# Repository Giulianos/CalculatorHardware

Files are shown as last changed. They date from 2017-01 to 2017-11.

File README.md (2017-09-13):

# Programmable Pocket Calculator Hardware

## Description
This programmable pocket sized calculator has the following features:
  - Credit card size, 8mm thick!
  - ARM Cortex M4 Microcontroller
  - microSD card reader
  - OLED Display
  - 44 mechanical* matrix keyboard (*tactile switches)
  - Lipo battery charging circuit

## Images
- Unsoldered, showing it's thickness
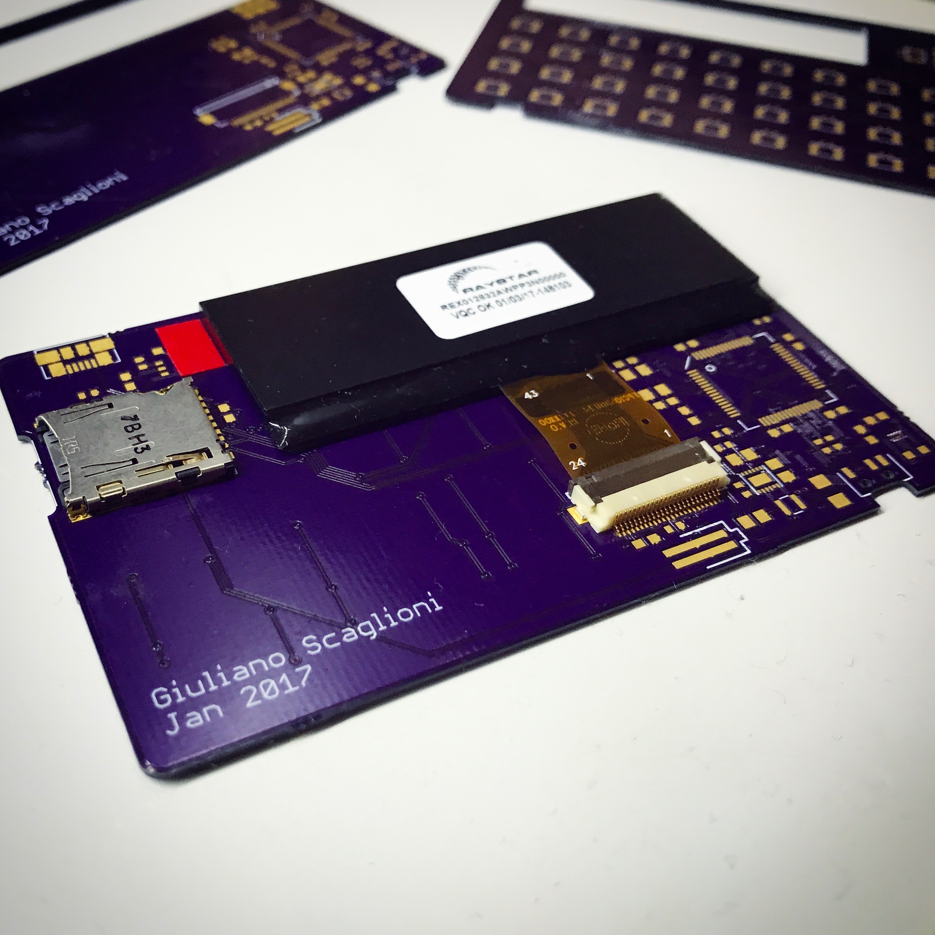
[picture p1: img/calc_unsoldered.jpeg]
Calc is 8mm thick!

- Soldered
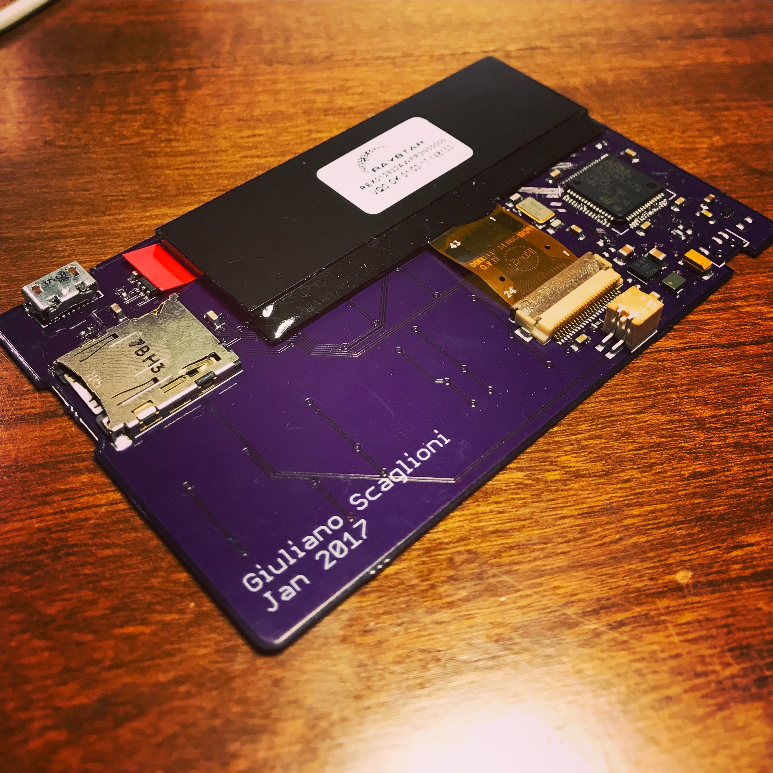
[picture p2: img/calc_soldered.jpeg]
Calc soldered

- Front view of PCB without tactile switches and with OLED in place
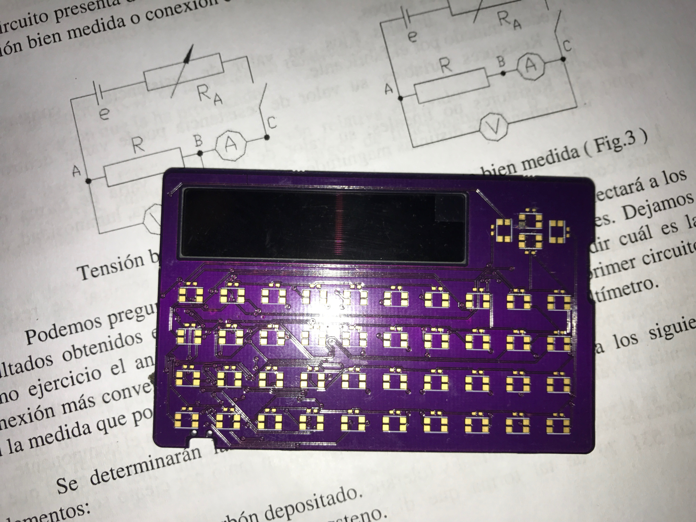
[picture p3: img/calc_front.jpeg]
Front view

- Back view of PCB unsoldered with battery, micro usb and micro sd card reader in place
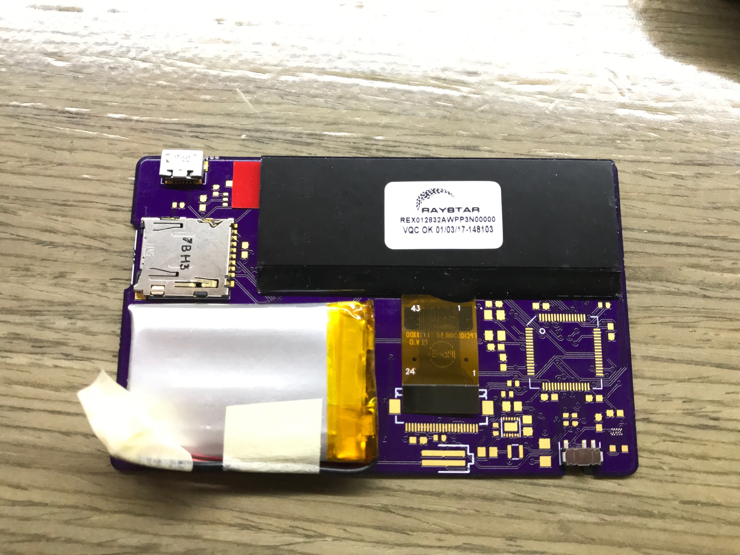
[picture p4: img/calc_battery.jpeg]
Back view

- Altium's 3D Render of the PCB
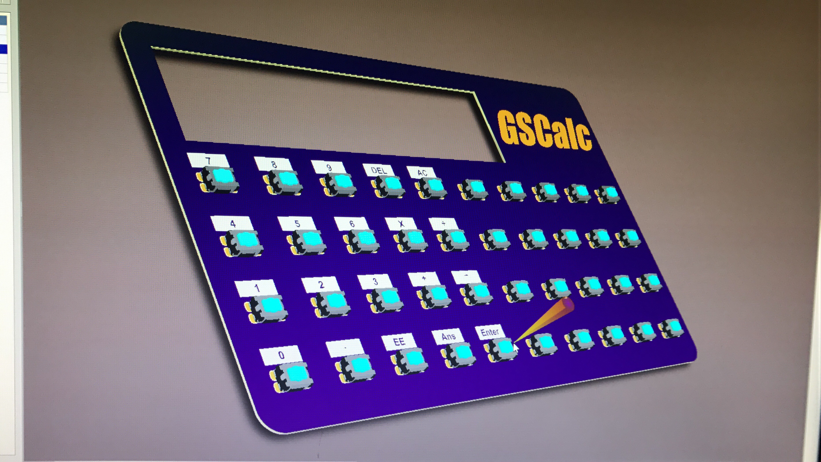
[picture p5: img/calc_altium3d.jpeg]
3D Render


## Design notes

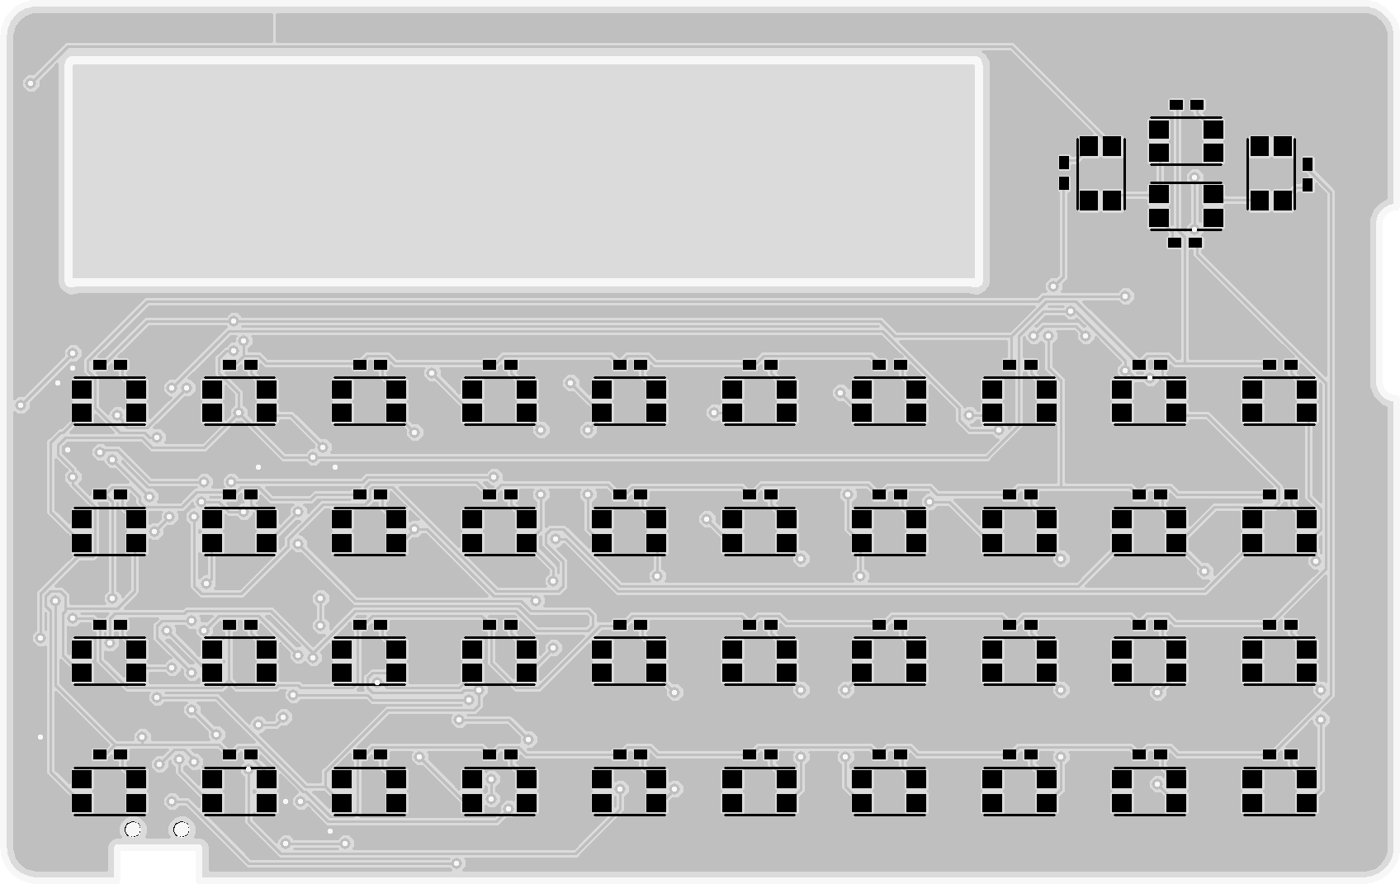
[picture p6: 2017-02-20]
pcbRenderTop.png

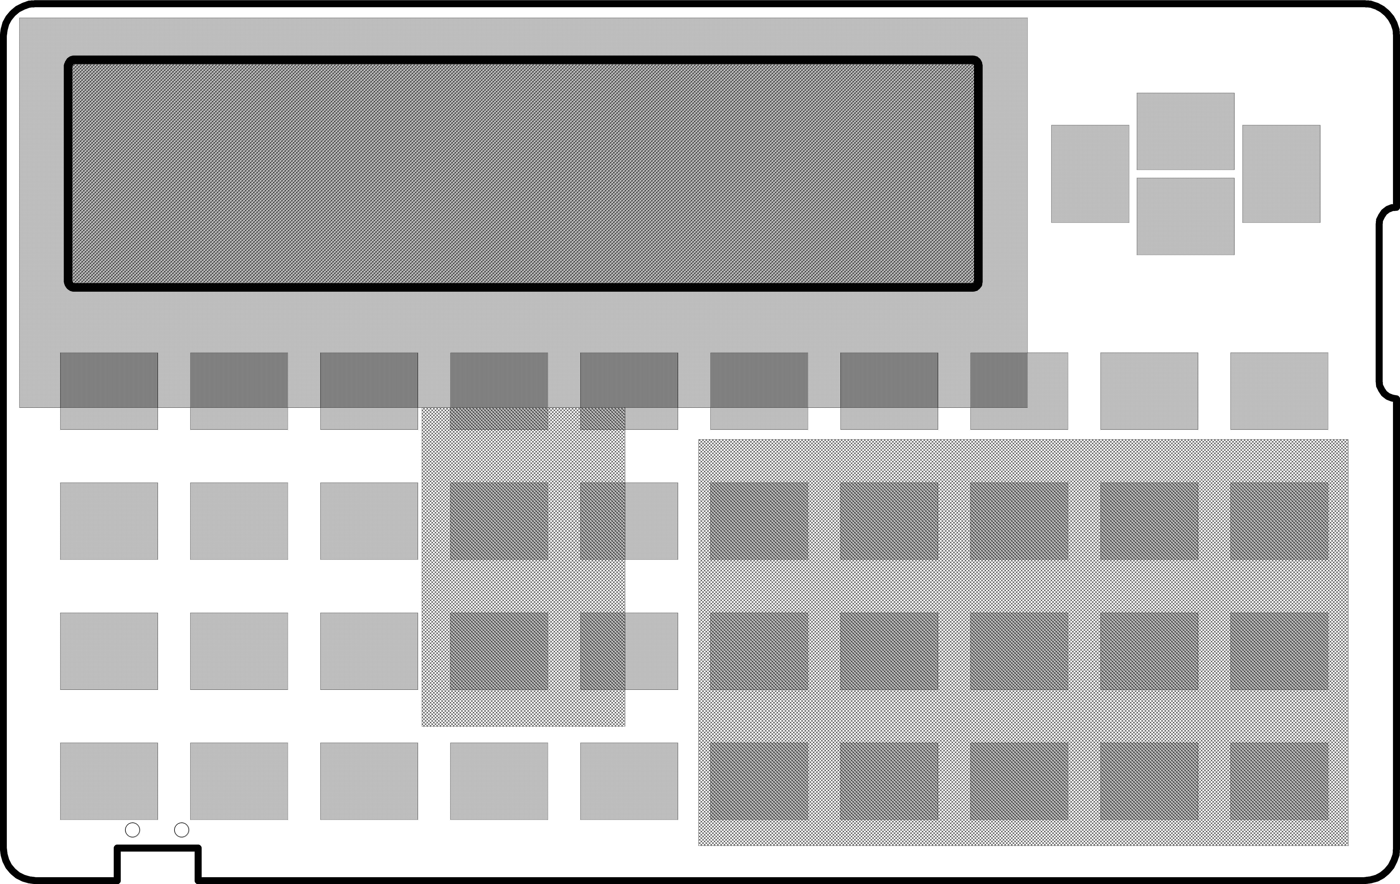
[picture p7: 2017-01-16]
render.png

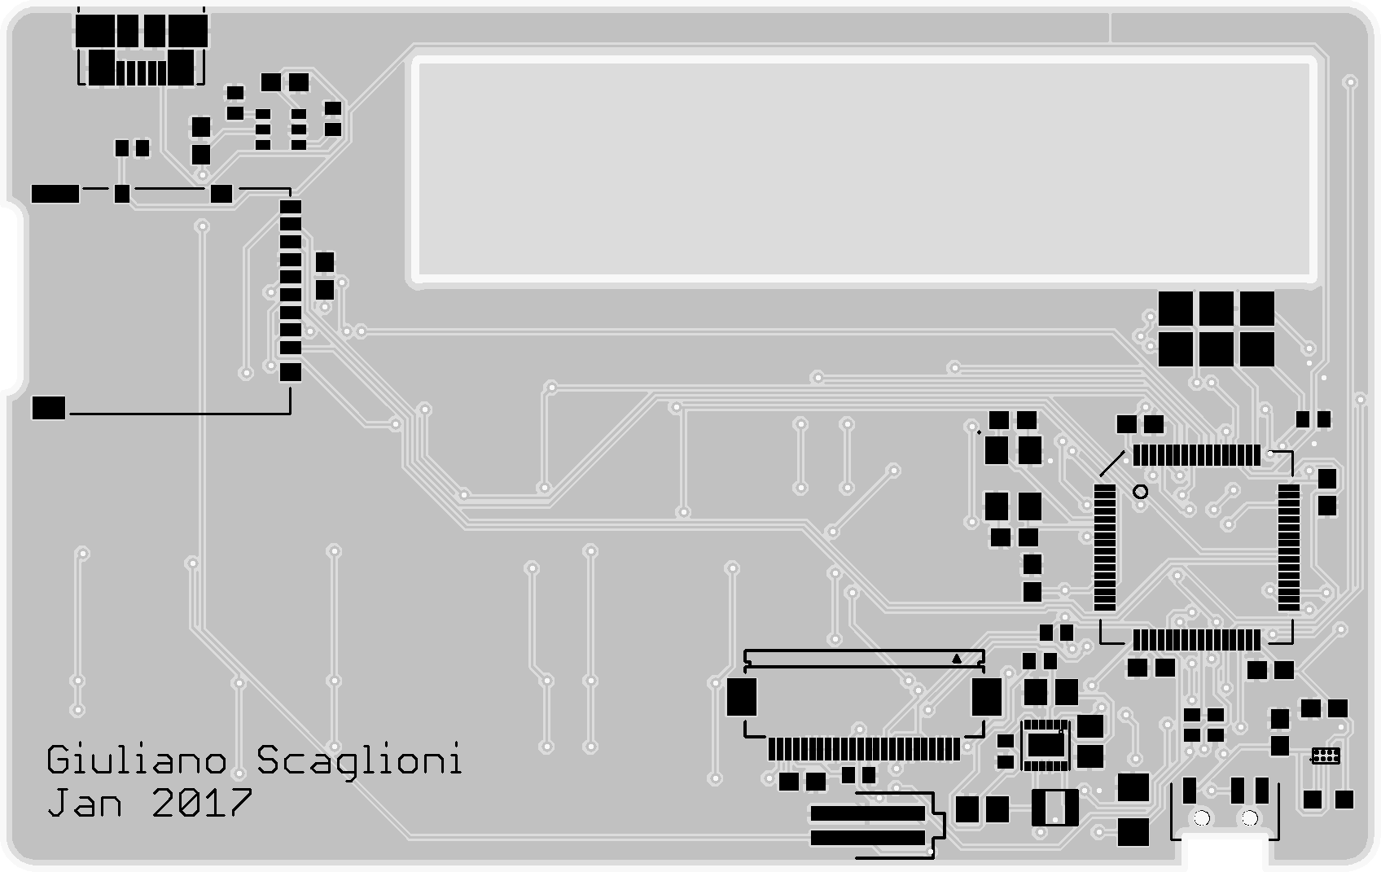
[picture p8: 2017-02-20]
pcbRenderBottom.png

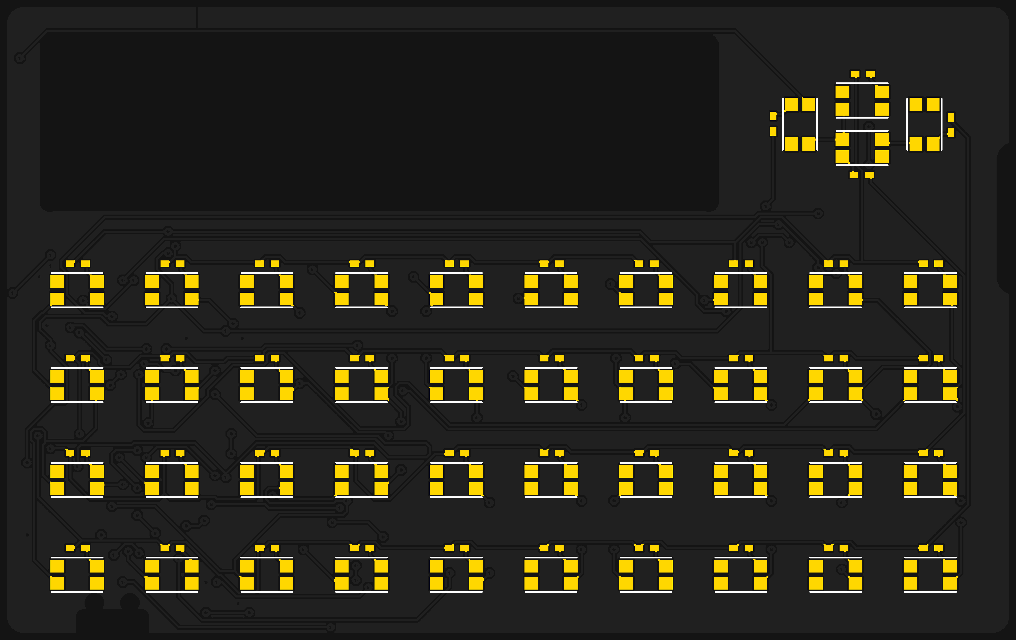
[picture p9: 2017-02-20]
eagleUp/eagleUp_mainboard_board_top.png

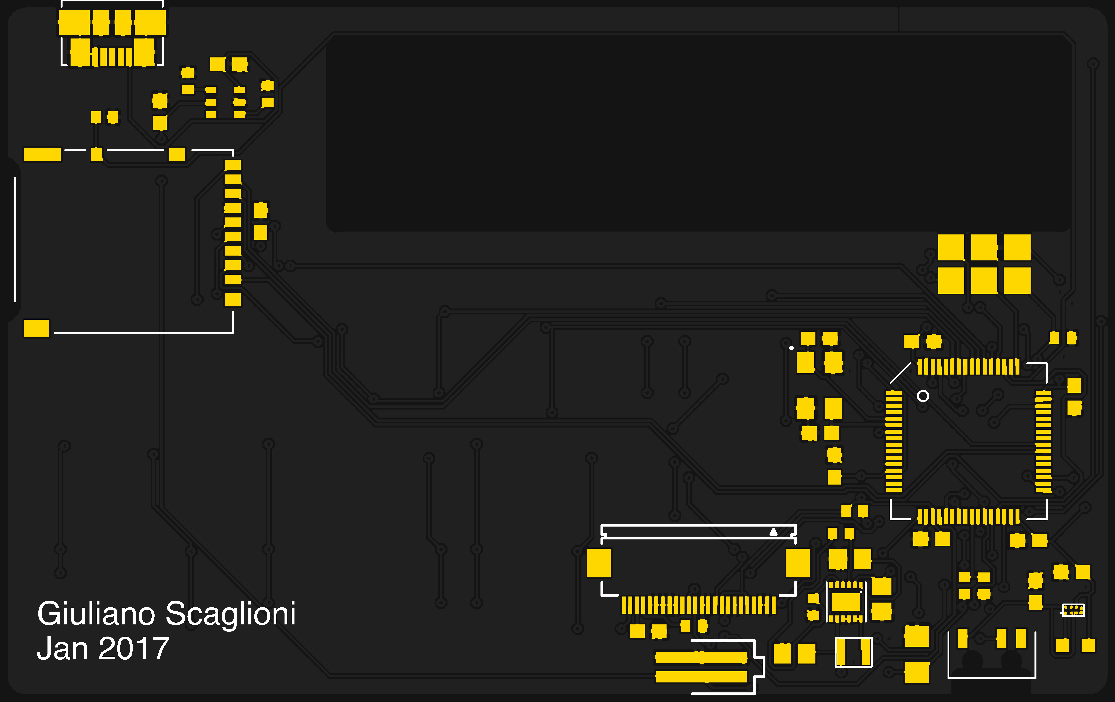
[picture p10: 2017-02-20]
pcbModel/eagleUp_mainboard_bottom_board.png

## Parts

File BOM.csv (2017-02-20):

Item | Valor | Codigo | Cantidad
Resistencia 0402 | 10k | 71-CRCW0402-10K-E3 | 20
Resistencia 0402 | 33k | 71-CRCW040233K0FKED | 10
Resistencia 0402 | 130k | 71-CRCW0402-130K-E3 | 10
Resistencia 0402 | 330k | 594-MCS04020C3303FE0 | 10
Resistencia 0402 | 300k | 71-CRCW0402-300K-E3 | 10
Resistencia 0402 | 1.2k | 71-CRCW0402-1.2K-E3 | 10
Resistencia 0603 | 910k | 71-CRCW0603-910K-E3 | 10
Capacitor 0603 | 18pF | 81-GRM39C180J50 | 10
Capacitor 0603 | 100nF | 80-C0603C104K4P | 20
Capacitor 0603 | 4.7uF | 81-GRM18R60J475KE19D | 10
Capacitor 0603 | 1uF | 81-GRM39R105K6.3 | 10
Capacitor 0603 | 10uF | 81-GRM188C80J106KA3D | 10
Capacitor 0805 | 10uF | 81-GRM21BR61A106KE19 | 10
Capacitor 0805 | 4.7uF | 81-GCM21BR71C475KA3L | 10
Capacitor 1206 Tant | 10uF | 80-T495A106K10ATE1K8 | 3
Inductor | 2.2uH | 81-1285AS-H-2R2MP2 | 5
Inductor | 4.7uH | 810-VLS252010HBU4R7M | 3
Crystal | 8MHz | 581-CX5032SA08HPSTZ1 | 3
Schotky Diode |  | 863-NSR05T40XV2T5G | 50
Momentary Switch |  | 710-434153017835 | 50
STM32 |  | 511-STM32L471RGT6 | 1
Card Reader |  | 798-DM3AT-SF-PEJM5 | 2
USB Connector |  | 538-47346-1001 | 2
Power Switch |  | 688-SSSS810701 | 3
OLED Display |  | 668-REX012832AWPP3N | 1
FFC Display Connector |  | 798-FH12-24S-0.5SH55 | 2
Buck 3.3v voltage regulator |  | 595-TPS627431YFPR | 2
Boost 13v voltage regulator |  | 511-STOD1317BTPUR | 2
Battery Charger Controller |  | 595-BQ21040DBVR | 2
Battery Connector |  | 538-87438-0243 | 3
Battery Wire Housing |  | 538-87439-0200 | 3
Battery Wire Contact |  | 538-87421-0000-CT | 100

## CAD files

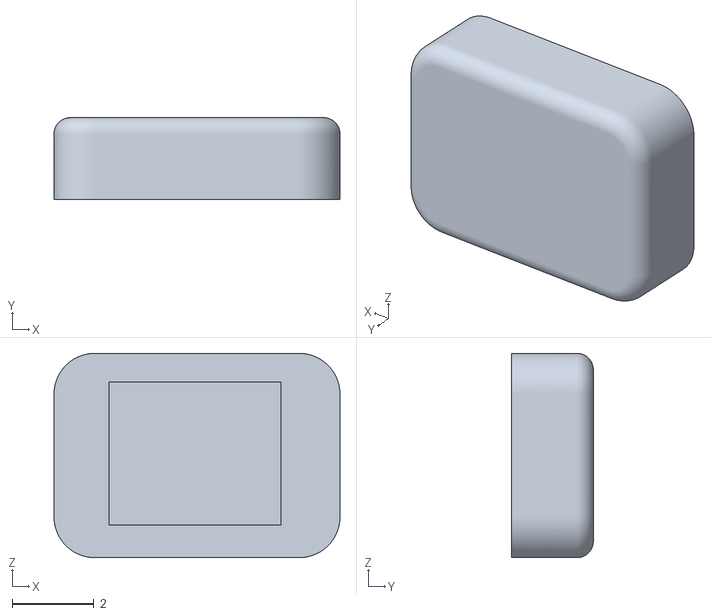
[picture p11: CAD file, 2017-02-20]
eagleUp/keyModel.stl
7.00 x 2.00 x 5.00

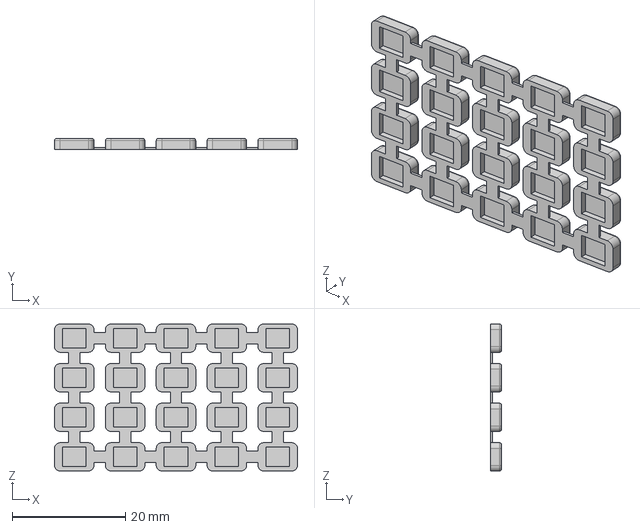
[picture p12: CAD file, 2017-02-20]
keypadModel.step
43.0 x 2.00 x 26.0 mm

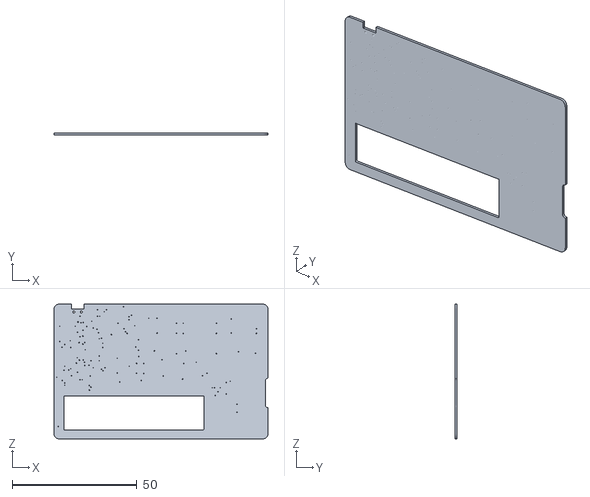
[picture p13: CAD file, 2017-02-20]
pcbModel.obj
85.7 x 0.8 x 54.0

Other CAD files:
keypadMatrixModel.stl

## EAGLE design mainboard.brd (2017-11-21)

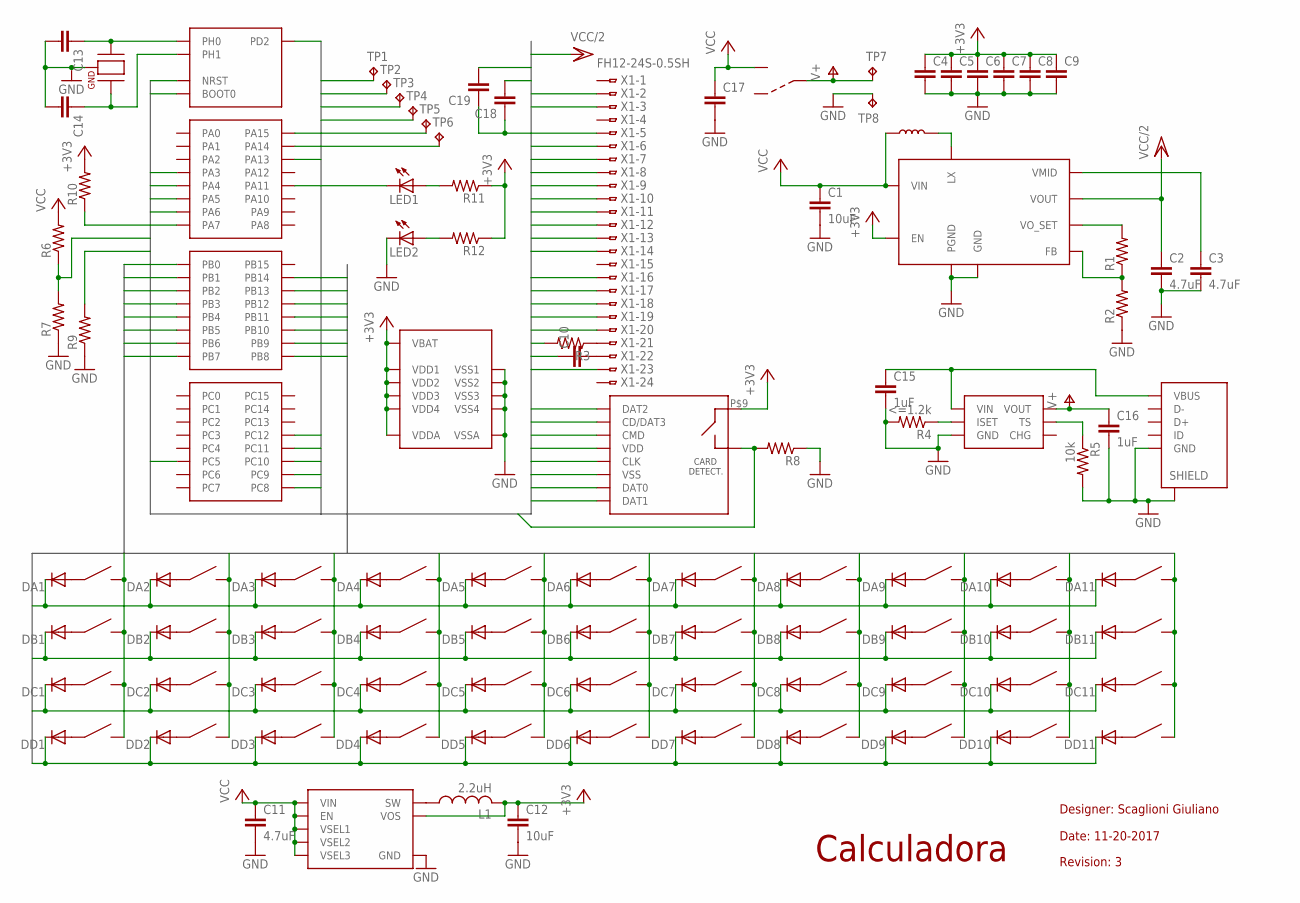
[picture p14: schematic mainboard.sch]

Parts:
BTA1, BTA2, BTA3, BTA4, BTA5, BTA6, BTA7, BTA8, BTA9, BTA10, BTA11: WURTH_SWITCH; WURTH_SWITCH_SMD
BTB1, BTB2, BTB3, BTB4, BTB5, BTB6, BTB7, BTB8, BTB9, BTB10, BTB11: WURTH_SWITCH; WURTH_SWITCH_SMD
BTC1, BTC2, BTC3, BTC4, BTC5, BTC6, BTC7, BTC8, BTC9, BTC10, BTC11: WURTH_SWITCH; WURTH_SWITCH_SMD
BTD1, BTD2, BTD3, BTD4, BTD5, BTD6, BTD7, BTD8, BTD9, BTD10, BTD11: WURTH_SWITCH; WURTH_SWITCH_SMD
C1: 10uF; C0805
C2, C3: 4.7uF; C0805
C4, C5, C6, C7, C8, C9, C10, C18, C19: C-EUC0603; C0603
C11: 4.7uF; C0603
C12: 10uF; C0603
C13, C14: CC0603; C0603
C15, C16: 1uF; C0603
C17: CC1206; C1206
DA1, DA2, DA3, DA4, DA5, DA6, DA7, DA8, DA9, DA10, DA11: DIODE-SOD523; SOD523
DB1, DB2, DB3, DB4, DB5, DB6, DB7, DB8, DB9, DB10, DB11: DIODE-SOD523; SOD523
DC1, DC2, DC3, DC4, DC5, DC6, DC7, DC8, DC9, DC10, DC11: DIODE-SOD523; SOD523
DD1, DD2, DD3, DD4, DD5, DD6, DD7, DD8, DD9, DD10, DD11: DIODE-SOD523; SOD523
L1: 2.2uH; L2012C
LED1, LED2: LED_ESML0603; LED_SML0603
R1, R2, R3, R6, R7, R8, R9, R10, R11, R12: R-US_R0402; R0402
R4: <=1.2k; R0402
R5: 10k; R0402
TP1, TP2, TP3, TP4, TP5, TP6, TP7, TP8: TPTP20SQ; TP20SQ
U$1: STM32L471RGT6; LQFP64
U$2: DM3AT-SF-PEJM5; DM3AT-SF-PEJM5_MICROSDREADER
U$3: MOLEX_47346-1001
U$4: STOD1317BTPUR; DFN12L
U$5: VLS252010HBU
U$6: TPS627431YFPR; BGA8
U$7: CX5032SA; CRYSTAL_5X3.2
U$8: BQ21040DBVR; 6-SOT-23
U$9: ALPS_SSSS810701
X1: FH12-24S-0.5SH

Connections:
+3V3: C4.1, C5.1, C6.1, C7.1, C8.1, C9.1, C12.1, C18.2, L1.2, R10.2, R11.1, R12.1, TP1.TP, U$1.P$1 (VBAT), U$1.P$13 (VDDA), U$1.P$19 (VDD1), U$1.P$32 (VDD2), U$1.P$48 (VDD3), U$1.P$64 (VDD4), U$2.P$4 (VDD), U$2.P$9, U$4.P6 (EN), U$6.C2 (VOS), X1.5, X1.9
BAT_SENS: R6.1, R7.2, U$1.P$25 (PC5)
BOOT0: R9.2, TP5.TP, U$1.P$60 (BOOT0)
GND: C1.2, C2.2, C3.2, C4.2, C5.2, C6.2, C7.2, C8.2, C9.2, C10.1, C11.2, C12.2, C13.2, C14.2, C15.2, C16.2, C17.2, C18.1, C19.1, LED2.C, R2.1, R3.2, R4.2, R5.2, R7.1, R8.1, R9.1, TP4.TP, TP8.TP, U$1.P$12 (VSSA), U$1.P$18 (VSS1), U$1.P$31 (VSS2), U$1.P$47 (VSS3), U$1.P$63 (VSS4), U$2.P$6 (VSS), U$3.MECH1, U$3.MECH2, U$3.MECH3, U$3.MECH4, U$3.MECH5, U$3.MECH6, U$3.P$5 (GND), U$4.P4 (GND), U$4.P9 (PGND), U$4.P10 (PGND), U$6.B2 (GND), U$7.P$2 (GND), U$7.P$4 (GND), U$8.P$5 (GND), X1.2, X1.3, X1.6, X1.7, X1.11, X1.12, X1.16, X1.17, X1.18, X1.19, X1.20
KEYCOL0: BTA1.P$2, BTA1.P$4, BTB1.P$2, BTB1.P$4, BTC1.P$2, BTC1.P$4, BTD1.P$2, BTD1.P$4, U$1.P$26 (PB0)
KEYCOL1: BTA2.P$2, BTA2.P$4, BTB2.P$2, BTB2.P$4, BTC2.P$2, BTC2.P$4, BTD2.P$2, BTD2.P$4, U$1.P$27 (PB1)
KEYCOL2: BTA3.P$2, BTA3.P$4, BTB3.P$2, BTB3.P$4, BTC3.P$2, BTC3.P$4, BTD3.P$2, BTD3.P$4, U$1.P$28 (PB2)
KEYCOL3: BTA4.P$2, BTA4.P$4, BTB4.P$2, BTB4.P$4, BTC4.P$2, BTC4.P$4, BTD4.P$2, BTD4.P$4, U$1.P$55 (PB3)
KEYCOL4: BTA5.P$2, BTA5.P$4, BTB5.P$2, BTB5.P$4, BTC5.P$2, BTC5.P$4, BTD5.P$2, BTD5.P$4, U$1.P$56 (PB4)
KEYCOL5: BTA6.P$2, BTA6.P$4, BTB6.P$2, BTB6.P$4, BTC6.P$2, BTC6.P$4, BTD6.P$2, BTD6.P$4, U$1.P$57 (PB5)
KEYCOL6: BTA7.P$2, BTA7.P$4, BTB7.P$2, BTB7.P$4, BTC7.P$2, BTC7.P$4, BTD7.P$2, BTD7.P$4, U$1.P$58 (PB6)
KEYCOL7: BTA8.P$2, BTA8.P$4, BTB8.P$2, BTB8.P$4, BTC8.P$2, BTC8.P$4, BTD8.P$2, BTD8.P$4, U$1.P$59 (PB7)
KEYCOL8: BTA9.P$2, BTA9.P$4, BTB9.P$2, BTB9.P$4, BTC9.P$2, BTC9.P$4, BTD9.P$2, BTD9.P$4, U$1.P$61 (PB8)
KEYCOL9: BTA10.P$2, BTA10.P$4, BTB10.P$2, BTB10.P$4, BTC10.P$2, BTC10.P$4, BTD10.P$2, BTD10.P$4, U$1.P$62 (PB9)
KEYCOL10: BTA11.P$2, BTA11.P$4, BTB11.P$2, BTB11.P$4, BTC11.P$2, BTC11.P$4, BTD11.P$2, BTD11.P$4, U$1.P$29 (PB10)
KEYROW0: DA1.C, DA2.C, DA3.C, DA4.C, DA5.C, DA6.C, DA7.C, DA8.C, DA9.C, DA10.C, DA11.C
KEYROW1: DB1.C, DB2.C, DB3.C, DB4.C, DB5.C, DB6.C, DB7.C, DB8.C, DB9.C, DB10.C, DB11.C, U$1.P$34 (PB13)
KEYROW2: DC1.C, DC2.C, DC3.C, DC4.C, DC5.C, DC6.C, DC7.C, DC8.C, DC9.C, DC10.C, DC11.C, U$1.P$33 (PB12)
KEYROW3: DD1.C, DD2.C, DD3.C, DD4.C, DD5.C, DD6.C, DD7.C, DD8.C, DD9.C, DD10.C, DD11.C, U$1.P$30 (PB11), U$1.P$35 (PB14)
unnamed: U$4.P11 (LX), U$4.P12 (LX), U$5.P$2
unnamed: R1.1, R2.2, U$4.P5 (FB)
unnamed: R3.1, X1.21
unnamed: R1.2, U$4.P3 (VO_SET)
unnamed: C10.2, X1.22
unnamed: C3.1, U$4.P1 (VMID)
unnamed: L1.1, U$6.A1 (SW)
unnamed: BTA1.P$1, BTA1.P$3, DA1.A
unnamed: BTA2.P$1, BTA2.P$3, DA2.A
unnamed: BTA3.P$1, BTA3.P$3, DA3.A
unnamed: BTA4.P$1, BTA4.P$3, DA4.A
unnamed: BTA5.P$1, BTA5.P$3, DA5.A
unnamed: BTA6.P$1, BTA6.P$3, DA6.A
unnamed: BTA7.P$1, BTA7.P$3, DA7.A
unnamed: BTA8.P$1, BTA8.P$3, DA8.A
unnamed: BTA9.P$1, BTA9.P$3, DA9.A
unnamed: BTA10.P$1, BTA10.P$3, DA10.A
unnamed: BTA11.P$1, BTA11.P$3, DA11.A
unnamed: BTB1.P$1, BTB1.P$3, DB1.A
unnamed: BTB2.P$1, BTB2.P$3, DB2.A
unnamed: BTB3.P$1, BTB3.P$3, DB3.A
unnamed: BTB4.P$1, BTB4.P$3, DB4.A
unnamed: BTB5.P$1, BTB5.P$3, DB5.A
unnamed: BTB6.P$1, BTB6.P$3, DB6.A
unnamed: BTB7.P$1, BTB7.P$3, DB7.A
unnamed: BTB8.P$1, BTB8.P$3, DB8.A
unnamed: BTB9.P$1, BTB9.P$3, DB9.A
unnamed: BTB10.P$1, BTB10.P$3, DB10.A
unnamed: BTB11.P$1, BTB11.P$3, DB11.A
unnamed: BTC1.P$1, BTC1.P$3, DC1.A
unnamed: BTC2.P$1, BTC2.P$3, DC2.A
unnamed: BTC3.P$1, BTC3.P$3, DC3.A
unnamed: BTC4.P$1, BTC4.P$3, DC4.A
unnamed: BTC5.P$1, BTC5.P$3, DC5.A
unnamed: BTC6.P$1, BTC6.P$3, DC6.A
unnamed: BTC7.P$1, BTC7.P$3, DC7.A
unnamed: BTC8.P$1, BTC8.P$3, DC8.A
unnamed: BTC9.P$1, BTC9.P$3, DC9.A
unnamed: BTC10.P$1, BTC10.P$3, DC10.A
unnamed: BTC11.P$1, BTC11.P$3, DC11.A
unnamed: BTD1.P$1, BTD1.P$3, DD1.A
unnamed: BTD2.P$1, BTD2.P$3, DD2.A
unnamed: BTD3.P$1, BTD3.P$3, DD3.A
unnamed: BTD4.P$1, BTD4.P$3, DD4.A
unnamed: BTD5.P$1, BTD5.P$3, DD5.A
unnamed: BTD6.P$1, BTD6.P$3, DD6.A
unnamed: BTD7.P$1, BTD7.P$3, DD7.A
unnamed: BTD8.P$1, BTD8.P$3, DD8.A
unnamed: BTD9.P$1, BTD9.P$3, DD9.A
unnamed: BTD10.P$1, BTD10.P$3, DD10.A
unnamed: BTD11.P$1, BTD11.P$3, DD11.A
unnamed: C13.1, U$1.P$5 (PH0), U$7.P$1 (P1)
unnamed: C14.1, U$1.P$6 (PH1), U$7.P$3 (P2)
unnamed: C15.1, U$3.P$1 (VBUS), U$8.P$6 (VIN)
unnamed: R5.1, U$8.P$1 (TS)
unnamed: R4.1, U$8.P$4 (ISET)
unnamed: LED1.A, R11.2
unnamed: LED1.C, U$1.P$44 (PA11)
unnamed: LED2.A, R12.2
NRST: R10.1, TP6.TP, U$1.P$7 (NRST)
PA3: U$1.P$17 (PA3), X1.10
PA13: TP2.TP, U$1.P$46 (PA13)
PA14: TP3.TP, U$1.P$49 (PA14)
SD_CLK: U$1.P$53 (PC12), U$2.P$5 (CLK)
SD_CMD: U$1.P$54 (PD2), U$2.P$3 (CMD)
SD_DAT0: U$1.P$39 (PC8), U$2.P$7 (DAT0)
SD_DAT1: U$1.P$40 (PC9), U$2.P$8 (DAT1)
SD_DAT2: U$1.P$51 (PC10), U$2.P$1 (DAT2)
SD_DAT3: U$1.P$52 (PC11), U$2.P$2 (CD/DAT3)
SD_SWITCH: R8.2, U$1.P$50 (PA15), U$2.P$10
SPI_CS: U$1.P$20 (PA4), X1.8
SPI_MISO: U$1.P$22 (PA6)
SPI_MOSI: U$1.P$23 (PA7), X1.14
SPI_SCK: U$1.P$21 (PA5), X1.13
V+: C16.1, TP7.TP, U$8.P$2 (VOUT), U$9.P$1 (COM)
VCC: C1.1, C11.1, C17.1, R6.2, U$4.P8 (VIN), U$5.P$1, U$6.A2 (VIN), U$6.B1 (EN), U$6.C1 (VSEL1), U$6.D1 (VSEL2), U$6.D2 (VSEL3), U$9.P$3 (L)
VCC/2: C2.1, C19.2, U$4.P2 (VOUT), X1.23

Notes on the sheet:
Calculadora
Designer: Scaglioni Giuliano
Date: 11-20-2017
Revision: 3

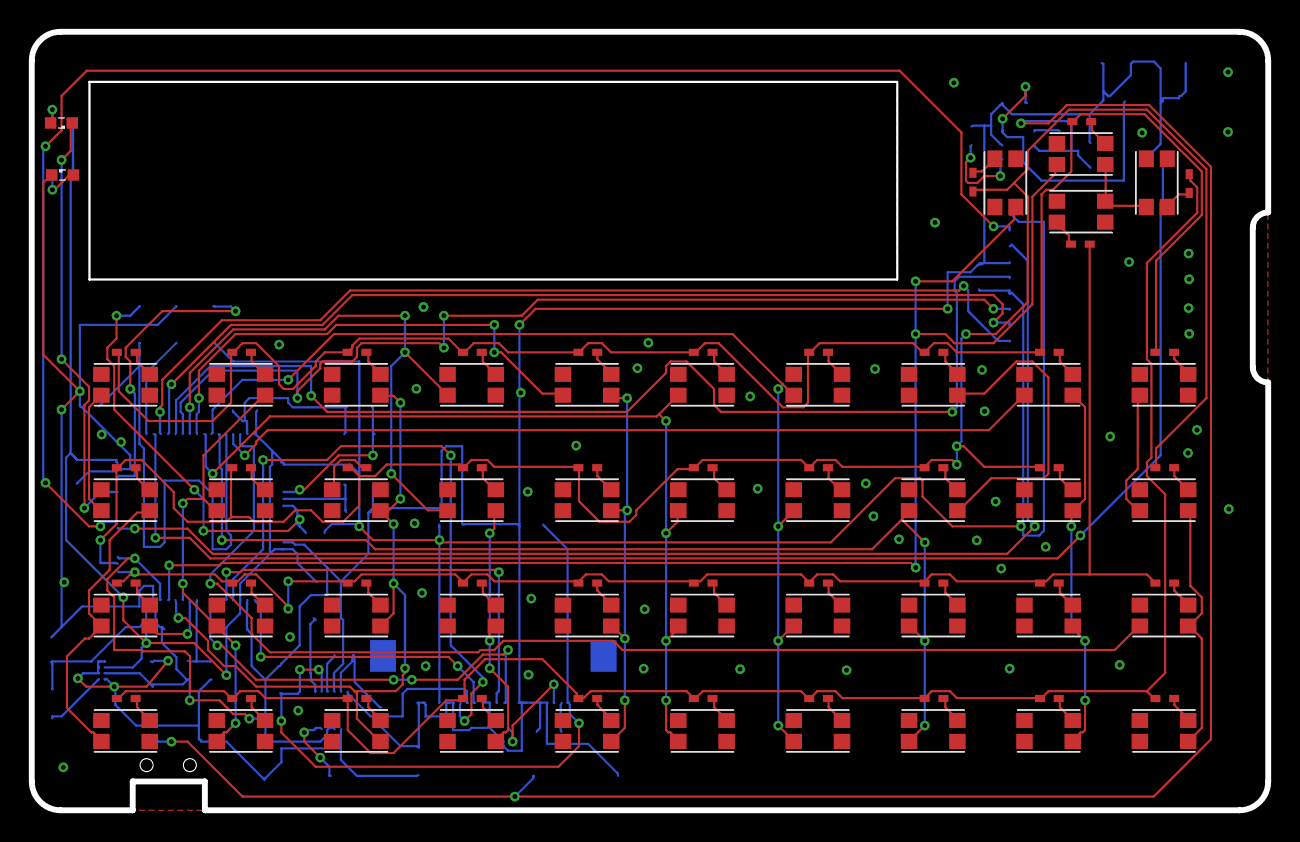
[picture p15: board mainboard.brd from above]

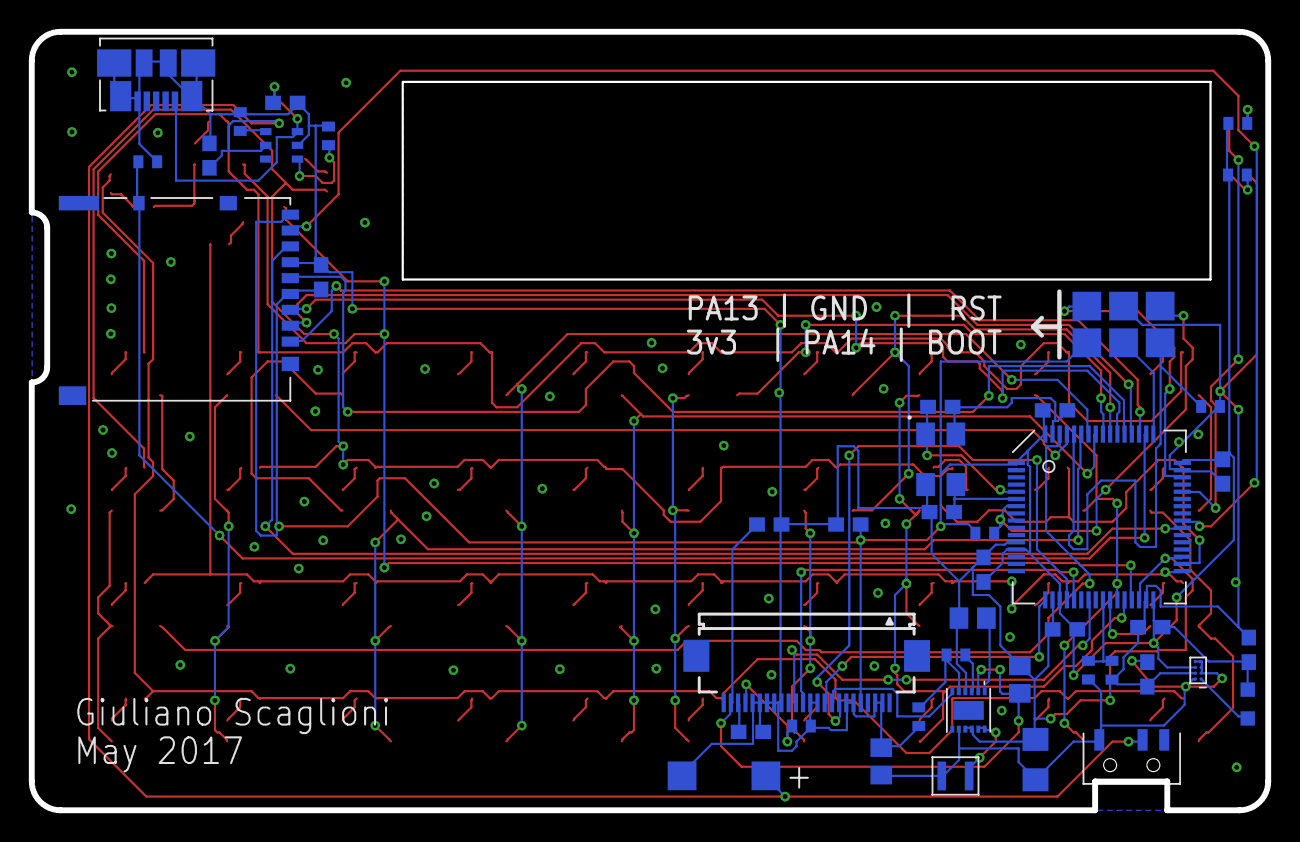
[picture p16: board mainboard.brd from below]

Board: 2 copper layers, 85.7 x 54.0 mm, 140 parts (50 on the bottom side), 95 nets.

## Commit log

2016-12-24 Added components
    -Tactile Switch
    -ARM Microcontroller
    -OLED Voltage regulator
2016-12-24 Added components
    -Micro SD Reader (Hirose)
    -MicroUSB Connector (Molex)
2016-12-25 Started mainboard design
    [mainboard.sch]
2017-01-06 Features added in schematic
    Power supplies (+3.3 and 12v)
    Button matrix
    Microprocessor and support circuitry
    Programming headers
    SD Card reader
    OLED Screen connector
    [mainboard.sch]
2017-01-06 Initial component placement
    [mainboard.brd]
2017-01-07 [Rev1] Finished shematic design
    Added usb charging
    PWR Button
    [mainboard.sch]
2017-01-07 [Rev1] Finished board
    [mainboard.brd]
2017-01-07 Modified silkscreen
    [mainboard.brd]
2017-01-16 Fixed Issues/New features
    Battery level sensing
    microSD card sensing
    Fixed issues:
    Boot0 pulldown resistor
    NRST pullup resistor
    [mainboard.sch]
2017-01-16 Updated PCB
    [mainboard.brd]
2017-02-20 Minor Stetic Modifications
    DIN-A4 frame in schematic and relocation.
    [mainboard.brd, mainboard.sch]
2017-02-20 Misc Files Added
    BOM
    PCB Renders
    PCB 3D models
    etc..
    [BOM.csv, BOM.xlsx, keyModel.stl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]
2017-05-22 [FIX] Missing EN connection in STOD1317BTPUR
    Conected EN Pin in STOD1317BTPUR to 3v3
    Added 0402 led for tests.
    Moved components from bga8 chip to allow visual inspection of soldering.
    [mainboard.brd, mainboard.sch]
2017-05-22 Added Silkscreen
    [mainboard.brd]
2017-05-23 Added GCalc Logo and Ground Plane
2017-11-20 Finished rev 3 schematic and component placement
    [mainboard.brd, mainboard.sch]
2017-11-21 Finished Rev 6 pcb routing
    [mainboard.brd, mainboard.sch]

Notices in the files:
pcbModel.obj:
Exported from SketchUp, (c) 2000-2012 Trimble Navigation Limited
